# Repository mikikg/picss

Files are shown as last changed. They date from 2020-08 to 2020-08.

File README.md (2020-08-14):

# PIC Soft Start

230VAC 2kVA Soft-start circuit with PIC16F15313 microcontroller.

This repository includes:
* Mplab X project for PIC firmware with source files and compiled HEX
* KiCAD project files for schematic and PCB

# Specification

* Input voltage: 230VAC
* Input frequency: 50Hz
* Max power output: 2kVA
* Phase angle control: 0° - 180° (100% - 0% power)
* Slope time: 0.1sec - 10sec

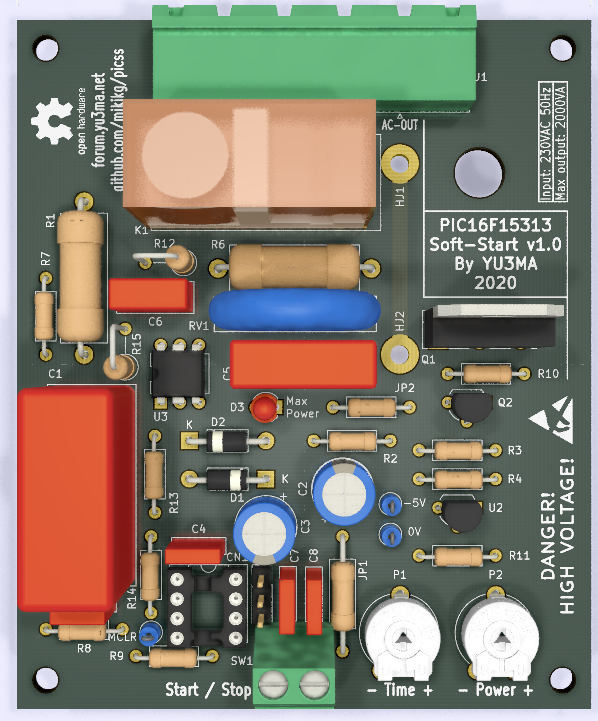
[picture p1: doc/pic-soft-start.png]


# Warning

This circuit operates on the mains high voltage line, do not touch any part of this device!

Please note that additional mains FUSE IS REQUIRED.

# More info

For more information please visit the project forum thread at https://forum.yu3ma.net/thread-1807-newpost.html

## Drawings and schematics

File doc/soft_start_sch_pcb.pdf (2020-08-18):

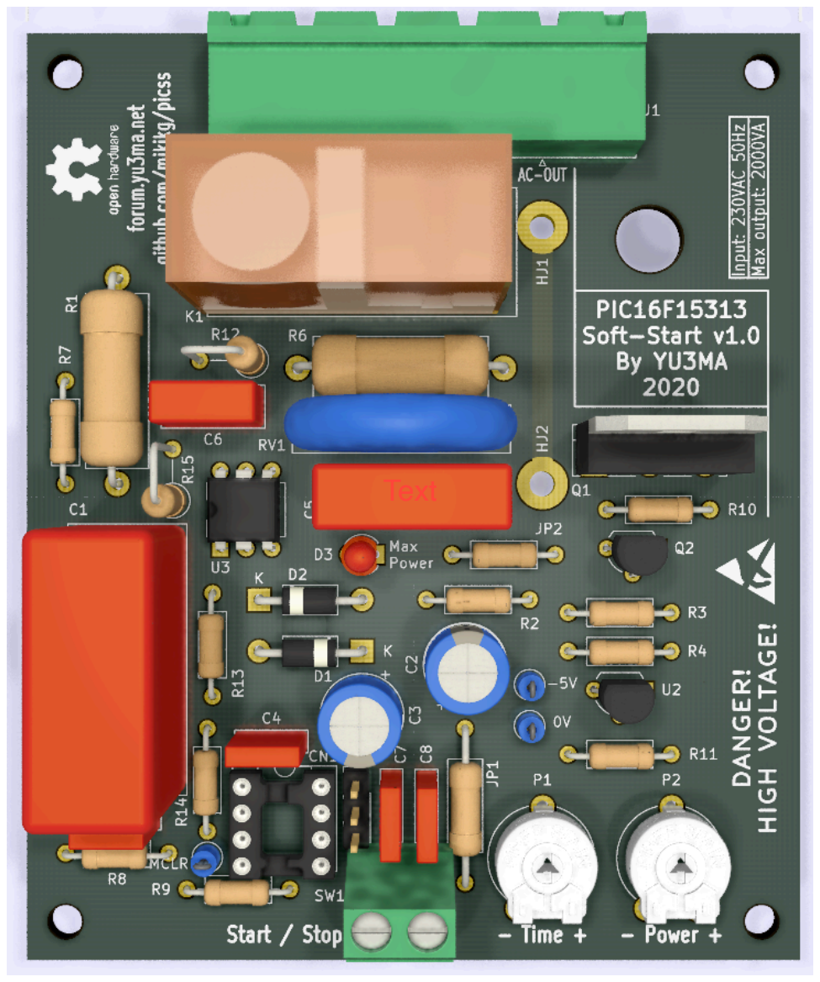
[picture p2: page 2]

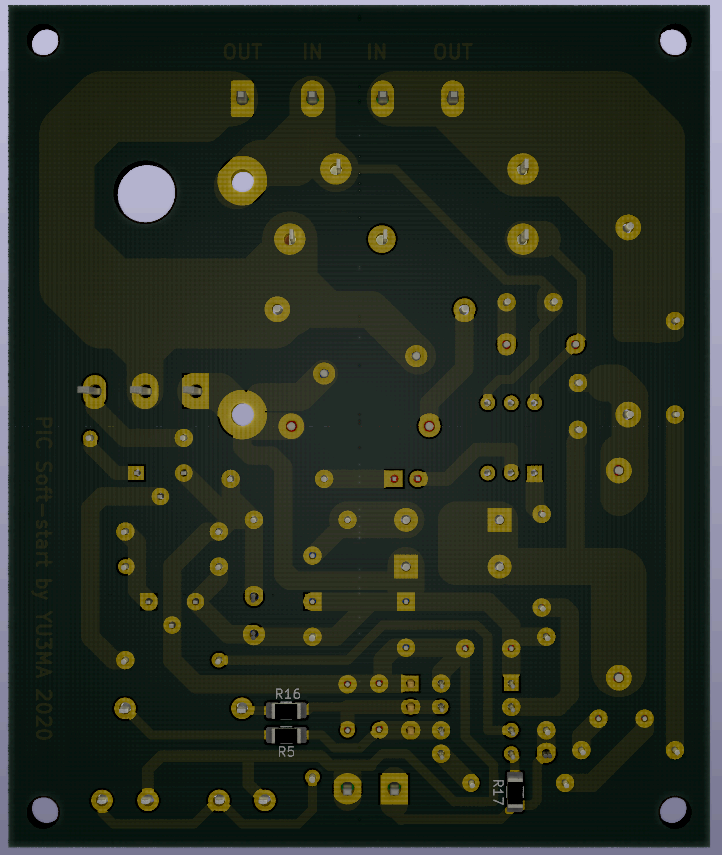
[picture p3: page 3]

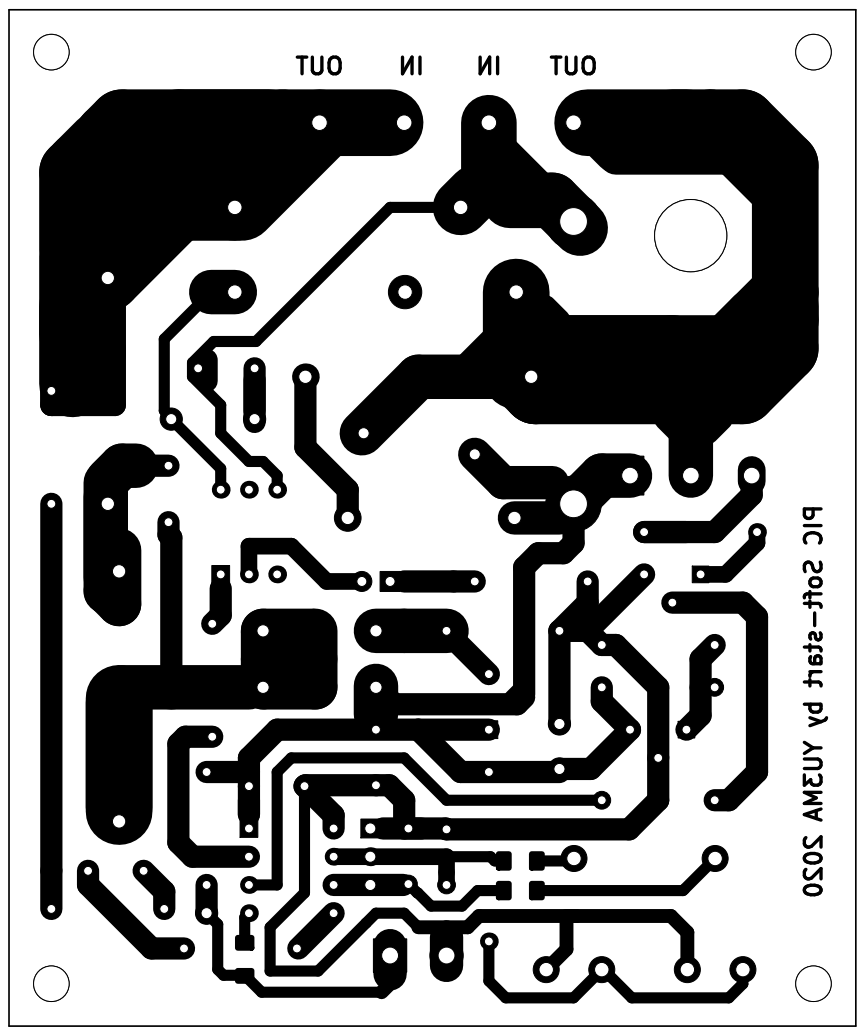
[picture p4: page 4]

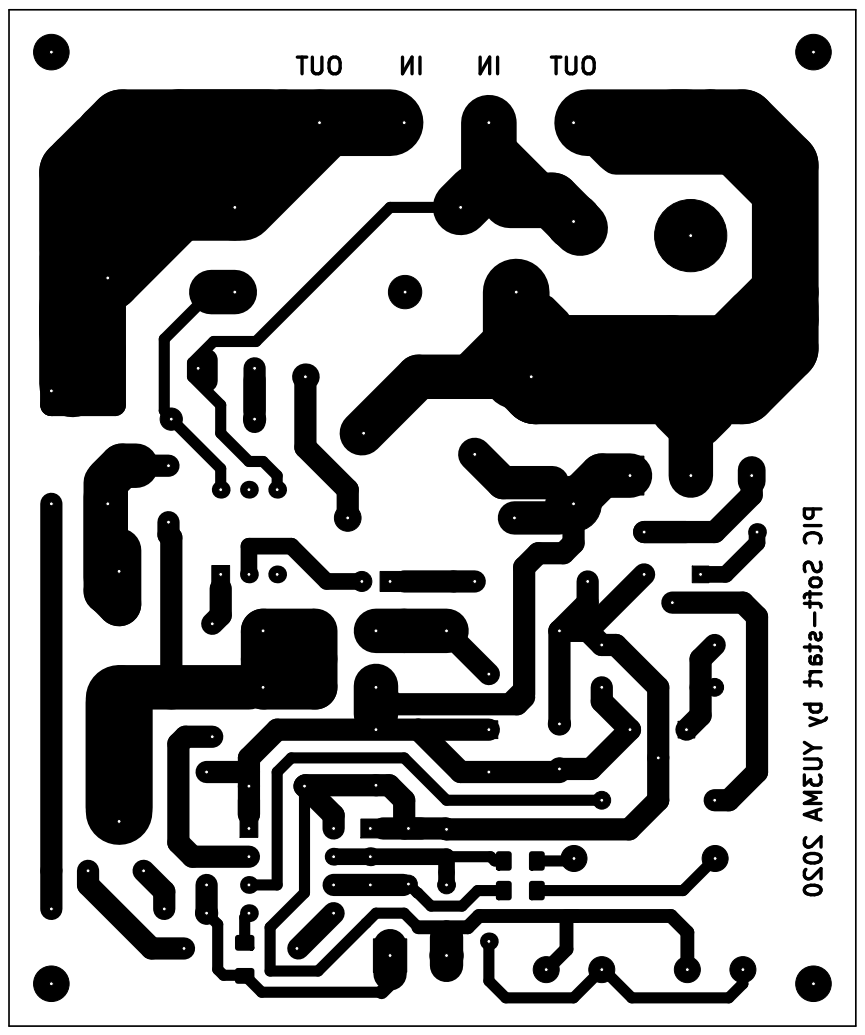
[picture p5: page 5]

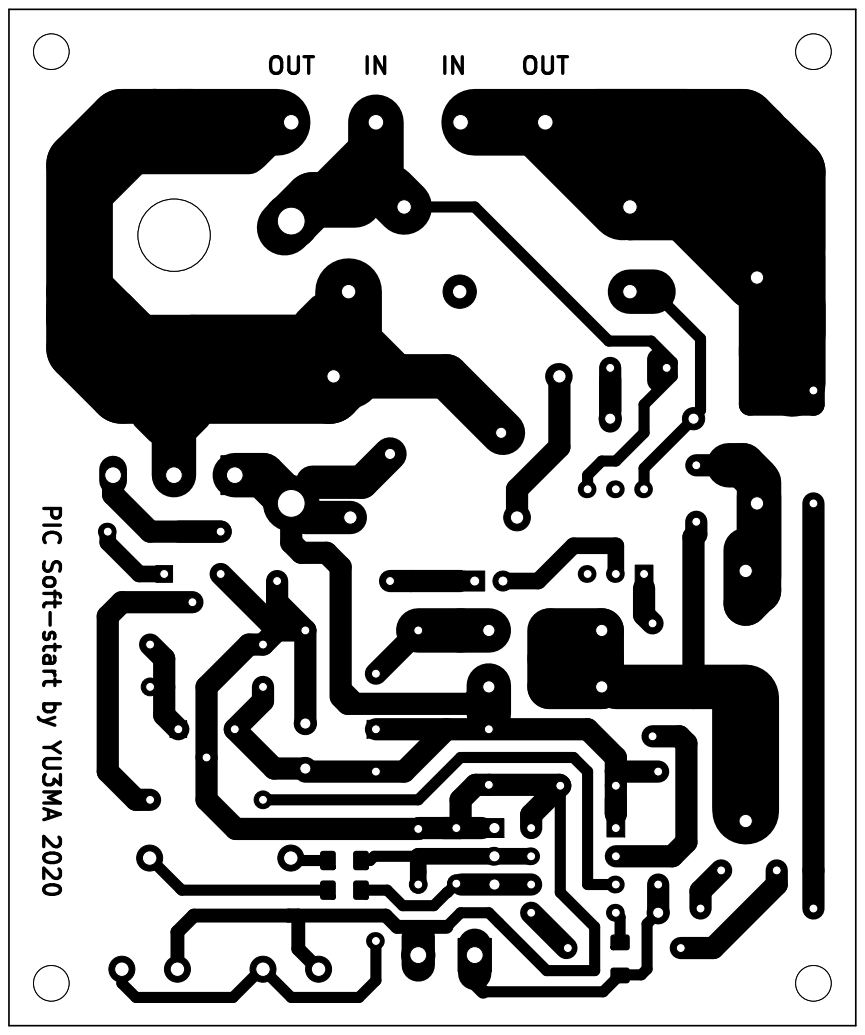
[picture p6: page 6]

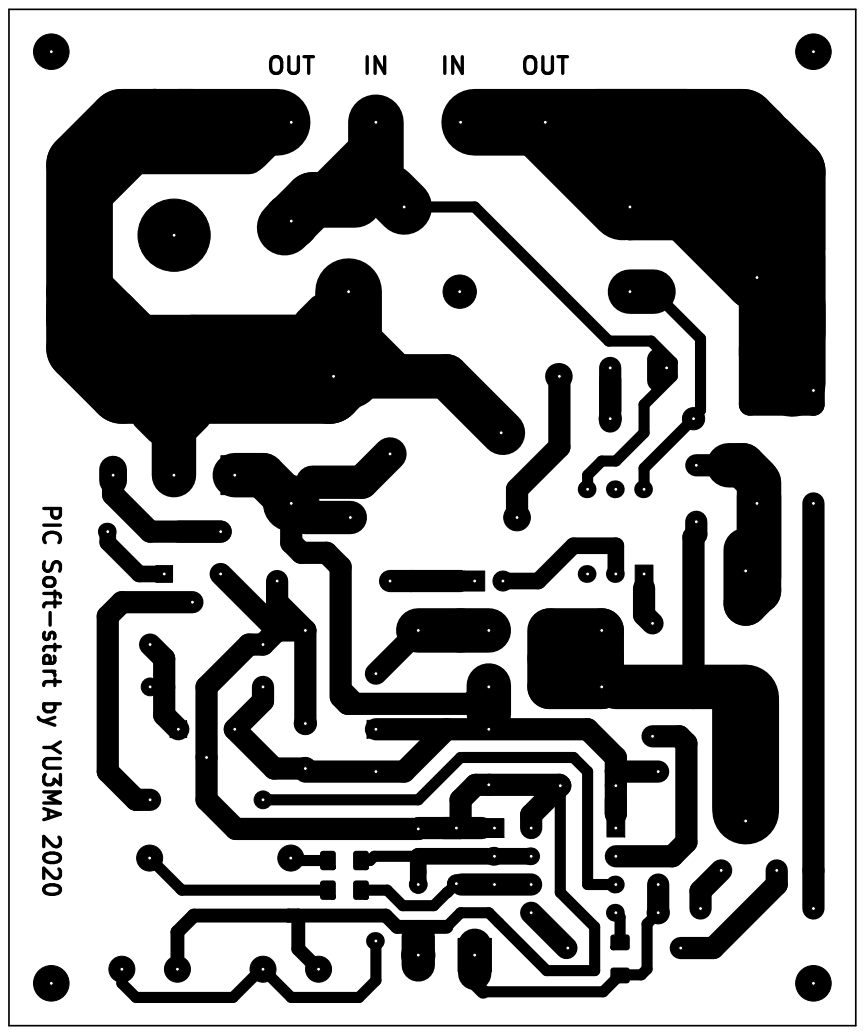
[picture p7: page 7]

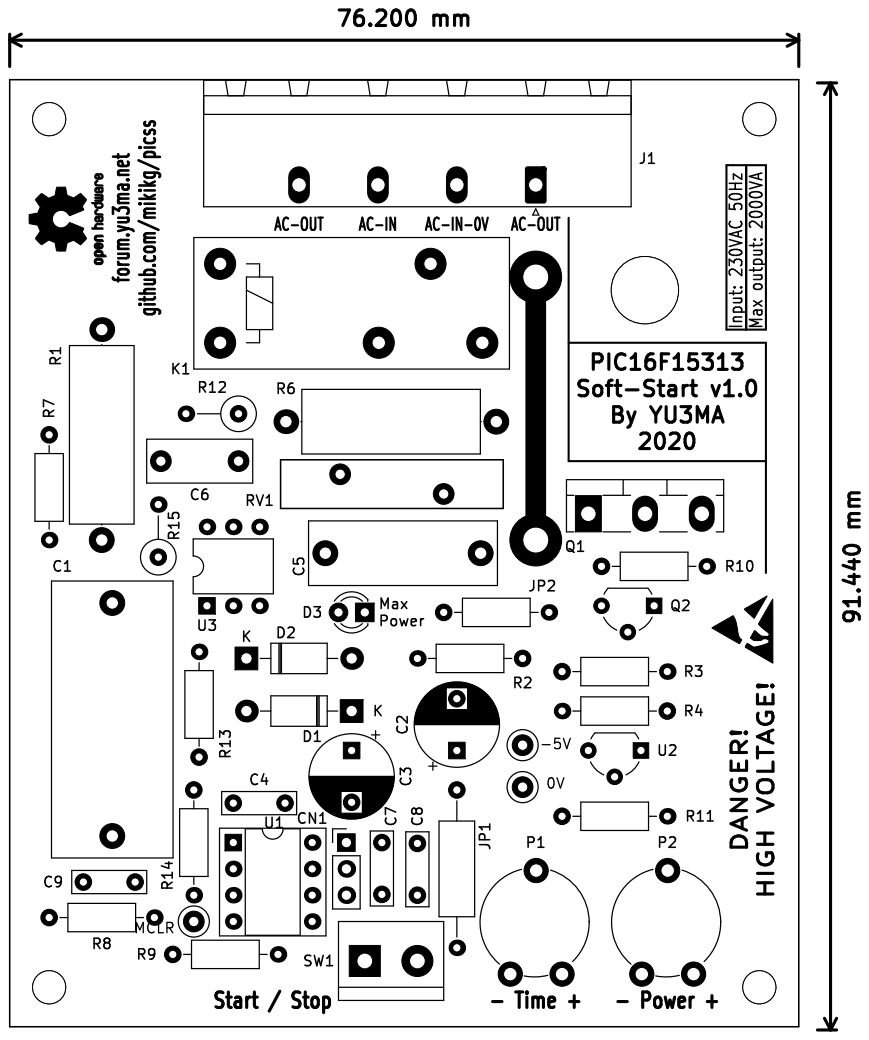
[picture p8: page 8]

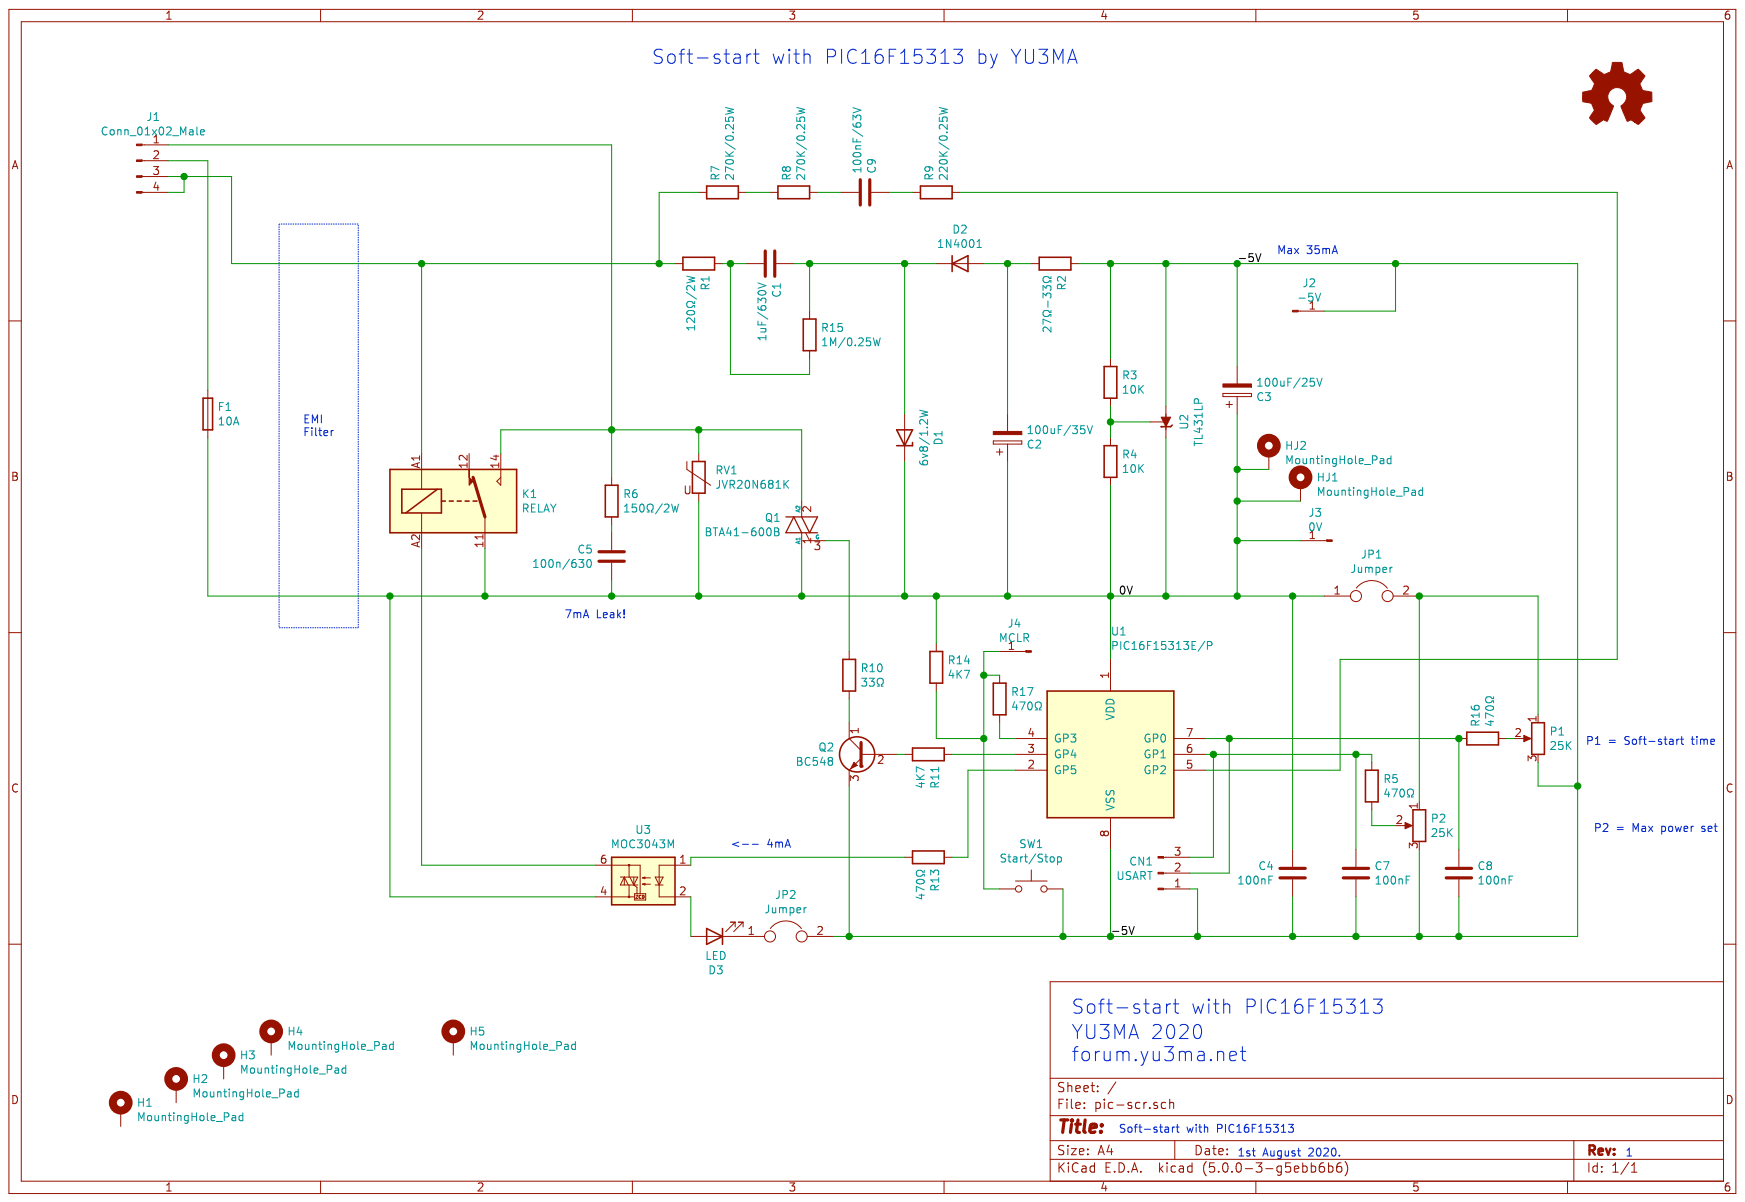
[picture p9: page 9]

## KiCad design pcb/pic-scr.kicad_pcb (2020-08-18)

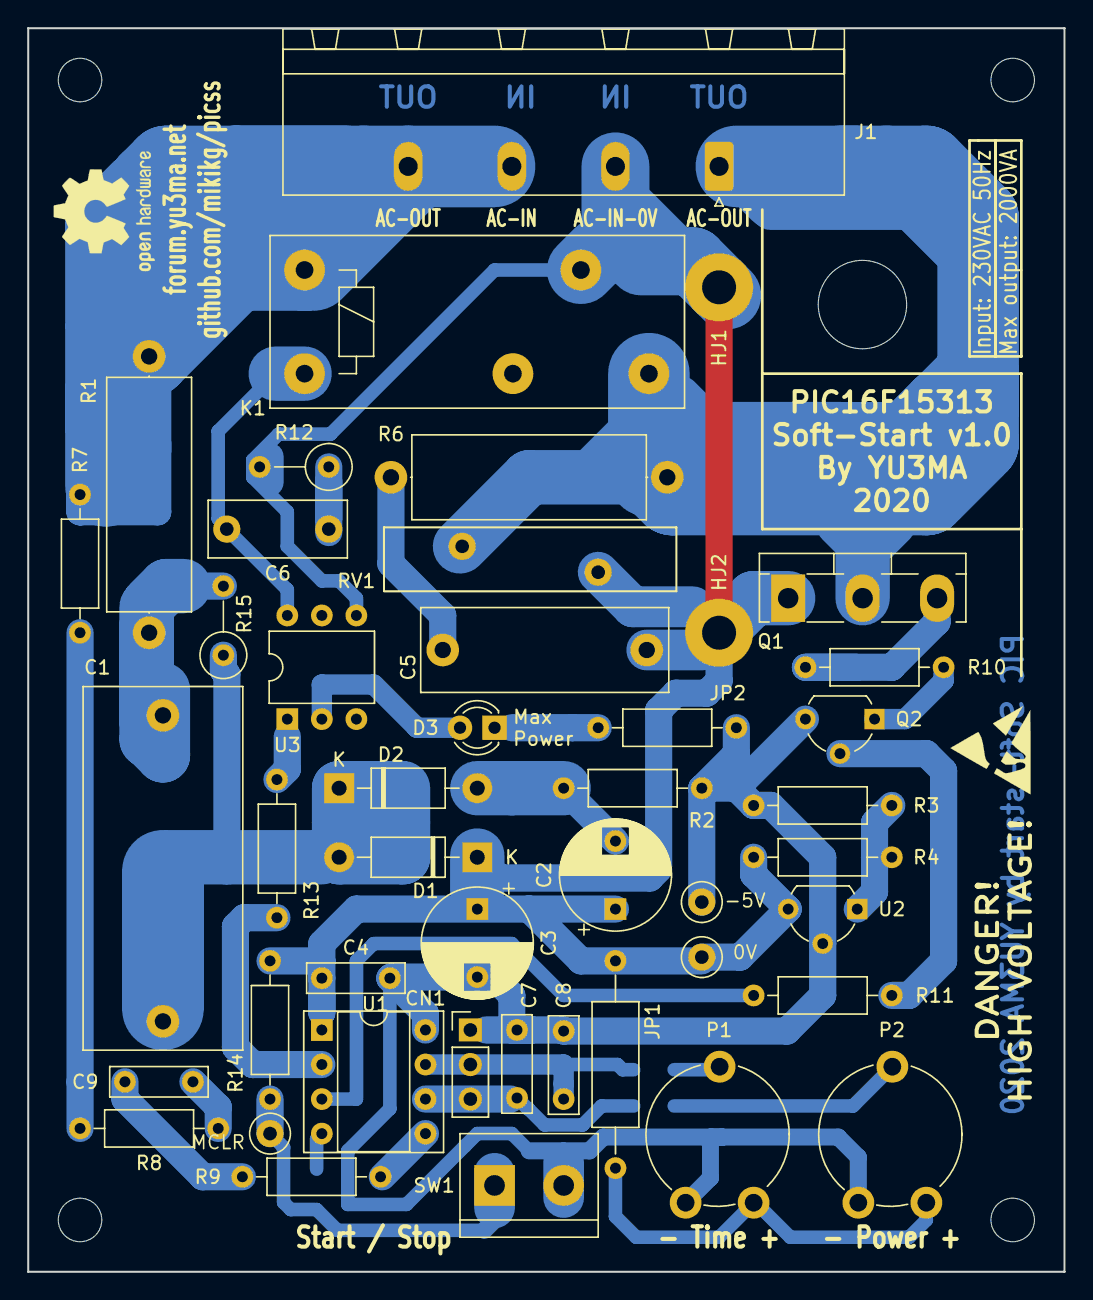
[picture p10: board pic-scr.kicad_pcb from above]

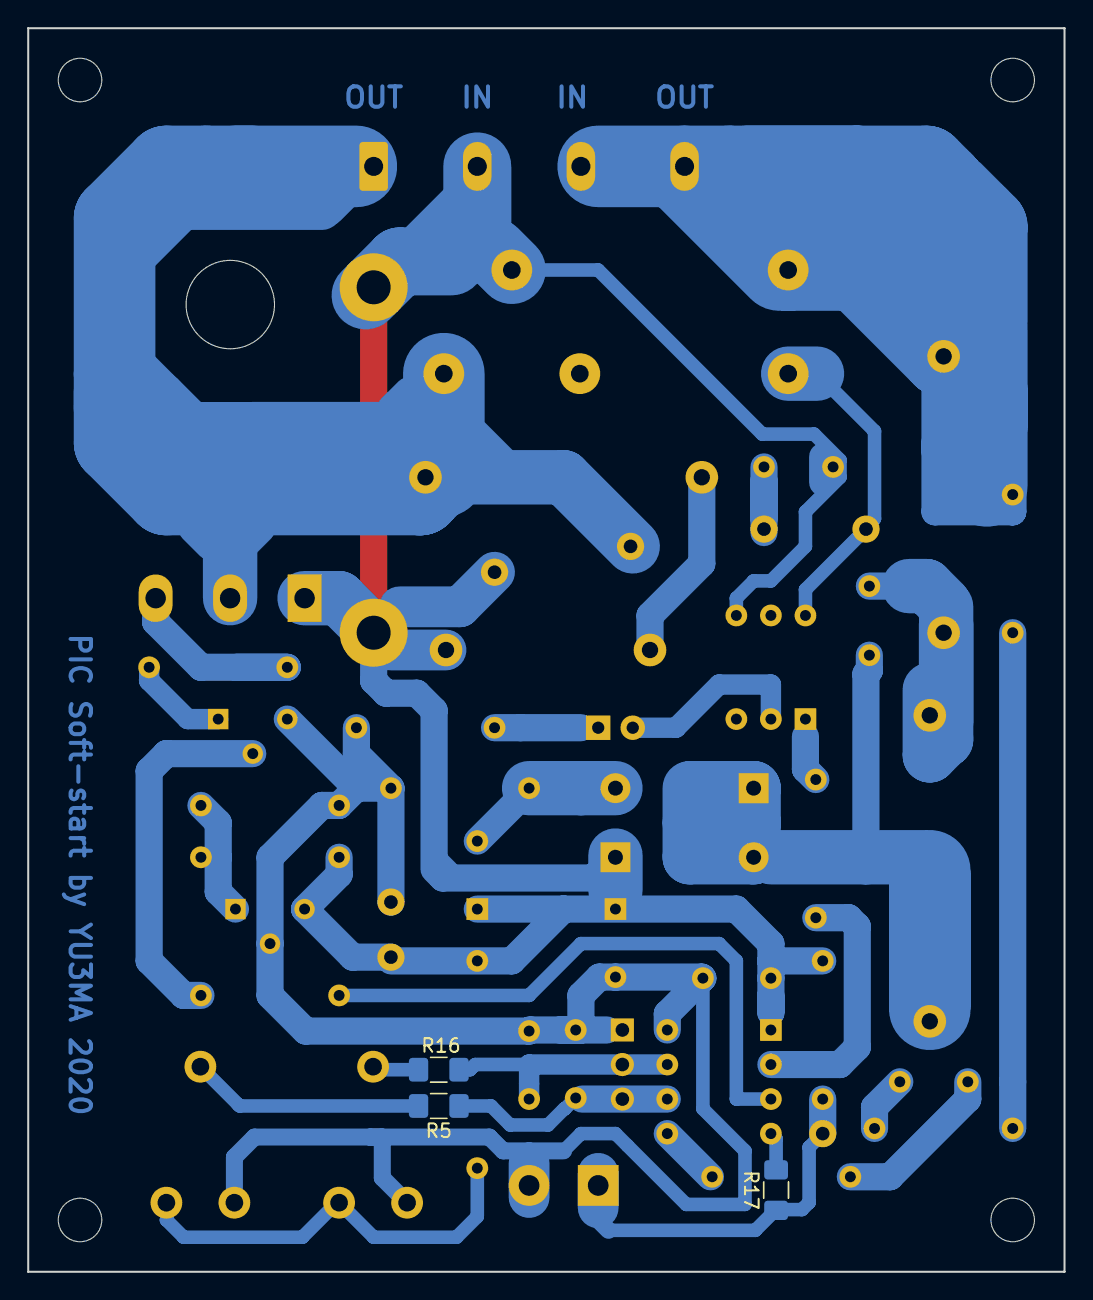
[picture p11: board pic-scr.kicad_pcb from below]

Board: 2 copper layers, 76.2 x 91.4 mm, 53 parts (3 on the bottom side), 30 nets.

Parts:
C1: 1uF/630V; C_Rect_L26.5mm_W11.5mm_P22.50mm_MKS4
C2: 100uF/35V; CP_Radial_D8.0mm_P5.00mm
C3: 100uF/25V; CP_Radial_D8.0mm_P5.00mm
C4, C7, C8: 100nF; C_Rect_L7.0mm_W2.0mm_P5.00mm
C5: 100n/630; C_Rect_L18.0mm_W6.0mm_P15.00mm_FKS3_FKP3
C6: 10nF/250V; C_Rect_L10.0mm_W4.0mm_P7.50mm_MKS4
C9: 100nF/63V; C_Rect_L7.0mm_W2.0mm_P5.00mm
CN1: USART; PinHeader_1x03_P2.54mm_Vertical
D1: 6v8/1.2W; D_DO-41_SOD81_P10.16mm_Horizontal
D2: 1N4001; D_DO-41_SOD81_P10.16mm_Horizontal
D3: LED; LED_D3.0mm
H1, H2, H3, H4: MountingHole_Pad; MountingHole_3.2mm_M3
H5: MountingHole_Pad; MountingHole_6.5mm
HJ1, HJ2: MountingHole_Pad; MountingHole_2.5mm_Pad
J1: Conn_01x02_Male; PhoenixContact_GMSTB_2,5_4-GF-7,62_1x04_P7.62mm_Horizontal_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
J2: -5V; TestPoint_Loop_D2.50mm_Drill1.0mm
J3: 0V; TestPoint_Loop_D2.50mm_Drill1.0mm
J4: MCLR; TestPoint_Loop_D2.50mm_Drill1.0mm
JP1: Jumper; R_Axial_DIN0309_L9.0mm_D3.2mm_P15.24mm_Horizontal
JP2: Jumper; R_Axial_DIN0207_L6.3mm_D2.5mm_P10.16mm_Horizontal
K1: RELAY; Relay_SPDT_Schrack-RP-II-1-FormC_RM5mm
P1, P2: 10K; Potentiometer_Piher_PT-10-V10_Vertical
Q1: BTA41-600B; TO-218-3_Vertical
Q2: BC548; TO-92L_Wide
R1: 220R/2W; R_Axial_DIN0617_L17.0mm_D6.0mm_P20.32mm_Horizontal
R2: 27R-33R; R_Axial_DIN0207_L6.3mm_D2.5mm_P10.16mm_Horizontal
R3, R4: 10K; R_Axial_DIN0207_L6.3mm_D2.5mm_P10.16mm_Horizontal
R5, R16, R17: 470R; R_1206_3216Metric_Pad1.42x1.75mm_HandSolder
R6: 150/2W; R_Axial_DIN0617_L17.0mm_D6.0mm_P20.32mm_Horizontal
R7, R8: 270K/0.25W; R_Axial_DIN0207_L6.3mm_D2.5mm_P10.16mm_Horizontal
R9: 220K/0.25W; R_Axial_DIN0207_L6.3mm_D2.5mm_P10.16mm_Horizontal
R10: 33R; R_Axial_DIN0207_L6.3mm_D2.5mm_P10.16mm_Horizontal
R11, R14: 4K7; R_Axial_DIN0207_L6.3mm_D2.5mm_P10.16mm_Horizontal
R12: 360R; R_Axial_DIN0309_L9.0mm_D3.2mm_P5.08mm_Vertical
R13: 470R; R_Axial_DIN0207_L6.3mm_D2.5mm_P10.16mm_Horizontal
R15: 3M/0.25W; R_Axial_DIN0309_L9.0mm_D3.2mm_P5.08mm_Vertical
RV1: JVR20N681K; RV_Disc_D21.5mm_W4.7mm_P10mm
SW1: Start/Stop; TerminalBlock_bornier-2_P5.08mm
U1: PIC16F15313E/P; DIP-8_W7.62mm_Socket
U2: TL431LP; TO-92L_Wide
U3: MOC3043M; DIP-6_W7.62mm

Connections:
-5V: C3.2, C4.2, C7.2, C8.2, CN1.1, J2.1, JP2.2, P1.3, P2.3, Q2.3, R2.1, R3.1, SW1.2, U1.8, U2.2
/0V: C2.1, C3.1, C4.1, C5.2, D1.1, HJ1.1, HJ2.1, J1.2, J3.1, JP1.1, K1.11, Q1.1, R4.2, R12.2, R14.1, RV1.2, U1.1, U2.3, U3.4
unnamed: C1.1, D1.2, D2.1, R15.1
unnamed: C1.2, R1.1, R15.2
unnamed: C2.2, D2.2, R2.2
unnamed: C5.1, R6.2
unnamed: C6.1, R12.1
unnamed: C6.2, K1.A2, U3.6
unnamed: C7.1, CN1.3, R5.1, U1.6
unnamed: C8.1, CN1.2, R16.1, U1.7
unnamed: C9.1, R9.1
unnamed: C9.2, R8.2
unnamed: D3.1, JP2.1
unnamed: D3.2, U3.2
unnamed: J1.1, K1.14, Q1.2, R6.1, RV1.1
unnamed: J1.3, J1.4, K1.A1, R1.2, R7.1
unnamed: J4.1, R14.2, R17.1, SW1.1
unnamed: JP1.2, P1.1, P2.1
unnamed: P1.2, R16.2
unnamed: P2.2, R5.2
unnamed: Q1.3, R10.1
unnamed: Q2.1, R10.2
unnamed: Q2.2, R11.2
unnamed: R3.2, R4.1, U2.1
unnamed: R7.2, R8.1
unnamed: R9.2, U1.5
unnamed: R11.1, U1.3
unnamed: R13.1, U1.2
unnamed: R13.2, U3.1
unnamed: R17.2, U1.4

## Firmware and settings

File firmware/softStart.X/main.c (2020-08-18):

/**
  Generated Main Source File

  Company:
    Microchip Technology Inc.

  File Name:
    main.c

  Summary:
    This is the main file generated using PIC10 / PIC12 / PIC16 / PIC18 MCUs

  Description:
    This header file provides implementations for driver APIs for all modules selected in the GUI.
    Generation Information :
        Product Revision  :  PIC10 / PIC12 / PIC16 / PIC18 MCUs - 1.81.4
        Device            :  PIC16F15313
        Driver Version    :  2.00
*/
/*
    (c) 2018 Microchip Technology Inc. and its subsidiaries. 
    
    Subject to your compliance with these terms, you may use Microchip software and any 
    derivatives exclusively with Microchip products. It is your responsibility to comply with third party 
    license terms applicable to your use of third party software (including open source software) that 
    may accompany Microchip software.
    
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
    IN NO EVENT WILL MICROCHIP BE LIABLE FOR ANY INDIRECT, SPECIAL, PUNITIVE, 
    INCIDENTAL OR CONSEQUENTIAL LOSS, DAMAGE, COST OR EXPENSE OF ANY KIND 
    WHATSOEVER RELATED TO THE SOFTWARE, HOWEVER CAUSED, EVEN IF MICROCHIP 
    HAS BEEN ADVISED OF THE POSSIBILITY OR THE DAMAGES ARE FORESEEABLE. TO 
    THE FULLEST EXTENT ALLOWED BY LAW, MICROCHIP'S TOTAL LIABILITY ON ALL 
    CLAIMS IN ANY WAY RELATED TO THIS SOFTWARE WILL NOT EXCEED THE AMOUNT 
    OF FEES, IF ANY, THAT YOU HAVE PAID DIRECTLY TO MICROCHIP FOR THIS 
    SOFTWARE.
*/

#include "mcc_generated_files/mcc.h"

//10us tajmer0 interupt
void TMR0_ISR(void) {
    // clear the TMR0 interrupt flag
    PIR0bits.TMR0IF = 0;
    
    // add your TMR0 interrupt custom code
    brojac1++;
    brojac2++;
    //brojac3++;
    //brojac4++;

    if ((brojac1 >= zadat_ugao) && (brojac1 <= (zadat_ugao+200)) && scr_out_enable ) {
        NCO1CONbits.N1EN = true; //opcija za češalj
        //SCR_OUT=1; //opcija za puls
    } else {
        NCO1CONbits.N1EN = false;
        //SCR_OUT=0;
    }
}

//Zero cros interupt
void ZCD_ISR(void) {
    if (brojac1 > 50) { //ZCD filter, prolaz pa sledeci tek moze za 50*10us
        //ok, ZCD akcija, ugasi triak gate signal
        
        //SCR_OUT = 0;
        NCO1CONbits.N1EN = false;
        
        //ocisti brojac
        brojac1 = 0;
        zadat_ugao = zadat_ugao_adc;
    }
    // Clear the ZCD interrupt flag
    PIR2bits.ZCDIF = 0;  
}

//LPF
#define FILTER_OVERSAMP 32
inline unsigned int low_pass_filter_1(unsigned int x) {
	static unsigned int samples[FILTER_OVERSAMP], i = 0, total = 0;
	/* Update the moving average */
	total += x - samples[i];
	samples[i] = x;
	/* Update the index */
	i = (i==(FILTER_OVERSAMP-1) ? 0 : i+1);
	return total/FILTER_OVERSAMP;
}

//LPF1
#define FILTER_OVERSAMP1 32
inline unsigned int low_pass_filter_2(unsigned int x1) {
	static unsigned int samples1[FILTER_OVERSAMP1], i1 = 0, total1 = 0;
	/* Update the moving average */
	total1 += x1 - samples1[i1];
	samples1[i1] = x1;
	/* Update the index */
	i1 = (i1==(FILTER_OVERSAMP1-1) ? 0 : i1+1);
	return total1/FILTER_OVERSAMP1;
}

/*
                         Main application
 */

#define inactive_angle 2000 // za brojac kada je neaktivan
#define max_angle 1000 //vreme potrebno za 1 poluperiodu 1000*10us=10ms
#define min_angle 50 //za podesavanje

void main(void) {
        
    // initialize the device
    SYSTEM_Initialize();
    // When using interrupts, enable the Global and Peripheral Interrupts
    INTERRUPT_GlobalInterruptEnable();
    INTERRUPT_PeripheralInterruptEnable();
    TMR0_StartTimer();
    
    //promenljive
    int taster_time, slope_counter, tmp_zadato, slope_increment;
    bool slope_up_active;

    while (1)
    {
        // ADC
        slope_increment = low_pass_filter_2(ADC_GetConversion(pot_slope));
        tmp_zadato = max_angle - low_pass_filter_1(ADC_GetConversion(pot_power));
        if (tmp_zadato < min_angle) tmp_zadato = min_angle;
        
        // Taster za start/stop slope
        if (RA3 == 0) { 
            if (taster_time ++ == 200) {
                //akcija
                scr_out_enable =! scr_out_enable;
                if (scr_out_enable == true) {
                    slope_up_active = true;
                    slope_counter = max_angle;
                }
            }
        } else taster_time = 0;

        // Slope
        if (slope_up_active == true) {
            if (brojac2 >= slope_increment) {
                slope_counter --;
                if (slope_counter <= 0 || slope_counter < tmp_zadato) {
                    //zavrsio slope
                    slope_up_active = false;
                } else {
                    //radi slope
                }
                brojac2 = 0;
            }
        }
        
        if (brojac1 > 1500) { 
            //ako odbrojao vise od 15ms bez ZCD, nema AC, gasi
            scr_out_enable = false;
            slope_up_active = false;
            brojac1 = 0;
        } 
        
        // Out
        if (scr_out_enable) {
            if (tmp_zadato > 990) { //kada je minimum tj off
                zadat_ugao_adc = inactive_angle;
            } else {
                if (slope_up_active) {
                    zadat_ugao_adc =  slope_counter;
                } else {
                    zadat_ugao_adc = tmp_zadato;
                }
            }
            //za relay kada je pri max snazi
            if (zadat_ugao_adc < 60) RLY_OUT = 1;
            if (zadat_ugao_adc > 80) RLY_OUT = 0;
        } else {
            //ugaseno
            slope_counter = 0;
            zadat_ugao_adc = inactive_angle;
            RLY_OUT = 0;
        }
        
    }
}

/**
 End of File
*/

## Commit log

2020-08-11 Initital import
    [pic-scr.kicad_pcb, pic-scr.sch]
2020-08-11 Added KiCad screenshot
2020-08-11 Updated KiCad screenshot
2020-08-18 Inverted RLY_OUT logic, enlarge triger pulse to 2ms
    [main.c]
2020-08-18 Updated shematic and PCB
    [pic-scr.kicad_pcb, pic-scr.sch]
2020-08-18 Updated schematic in PDF
